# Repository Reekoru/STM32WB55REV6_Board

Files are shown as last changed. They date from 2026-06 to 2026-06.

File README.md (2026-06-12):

# STM32WB55REV6 Custom Development Board

A compact, custom-designed development board for the **STM32WB55REV6** dual-core Bluetooth Low Energy (BLE) and Zigbee microcontroller. Designed in KiCad, this board features a modern USB-C interface for power/data, a dedicated UART interface for debugging, and a space-saving Tag-Connect TC2030 footprint for SWD programming.

## Features

* **MCU:** STM32WB55REV6 (Dual-core Arm® Cortex®-M4 @ 64 MHz with FPU, Cortex-M0+ @ 32 MHz for network/radio).
* **Connectivity:** On-board RF circuitry and antenna for 2.4 GHz BLE 5.4, Zigbee, and Thread.
* **Power:** USB-C connector with TPS78233DDC 3.3V regulator supplying up to 150 mA.
* **Programming/Debugging:** SWD via a headless **Tag-Connect TC2030** footprint (no-legs/legged variant).
* **Serial Communication:** Dedicated UART breakout header for easy terminal debugging.
* **Peripherals:** 
    * 1x User LED (connected to Pin `PB9`)
    * USB-UART (connected to Pin `PA9` [TX], Pin `PA10` [RX])
    * 1x Reset Button, 1x Boot Button
    * External 32.768 kHz LSE Crystal, 32 MHz HSE Crystal

---

## Hardware Overview

### Pinout Configuration

| Interface | Pin Name | STM32WB55 Pin | Description |
| :--- | :--- | :--- | :--- |
| **UART** | TX / RX | PA9 / PA10 | Debug Serial Port |
| **SWD** | SWO / SWDIO / SWCLK | PB3 / PA13 / PA14 | Tag-Connect TC2030 Programming |
| **User LED** | LED1 | PB9 | Active [High/Low] indicator |

### Power Supply
The board is powered via the **USB-C** connector. The input 5V is regulated down to 3.3V for the MCU and RF front end. 
* **Maximum input voltage:** 5.5V
* **Operating voltage:** 3.3V

---

## Programming and Debugging

### Required Hardware
To flash and debug this board, you will need:
1.  An ST-LINK V2, V3, or a Segger J-Link debugger.
2.  A **Tag-Connect TC2030-IDC** (or TC2030-IDC-NL) cable along with the corresponding retaining clip if using the no-legs version.

### SWD Pinout (TC2030 Footprint)
The Tag-Connect footprint maps to the following standard SWD layout:
* Pin 1: VCC (3.3V)
* Pin 2: SWDIO
* Pin 3: NRST (Reset)
* Pin 4: SWCLK
* Pin 5: GND
* Pin 6: SWO (Optional trace capture)

### Flashing via STM32CubeProgrammer
1. Connect the TC2030 cable to the board and your ST-LINK debugger.
2. Open **STM32CubeProgrammer**, select **ST-LINK** as the interface, and click **Connect**.
3. Browse for your compiled binary/hex file and click **Start Programming**.

---

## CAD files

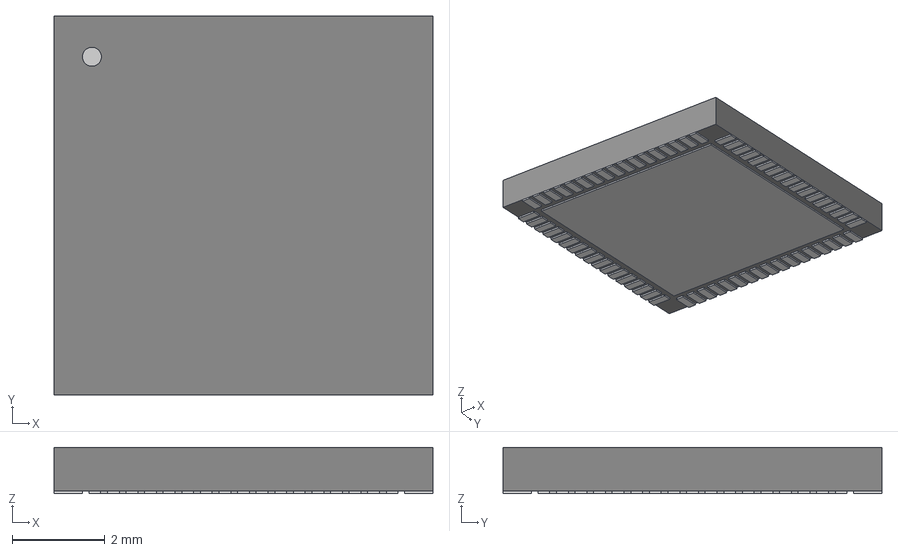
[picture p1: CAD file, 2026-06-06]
STM32WB55REV6/VFQFN68-8x8mm.step
8.15 x 8.15 x 0.993 mm

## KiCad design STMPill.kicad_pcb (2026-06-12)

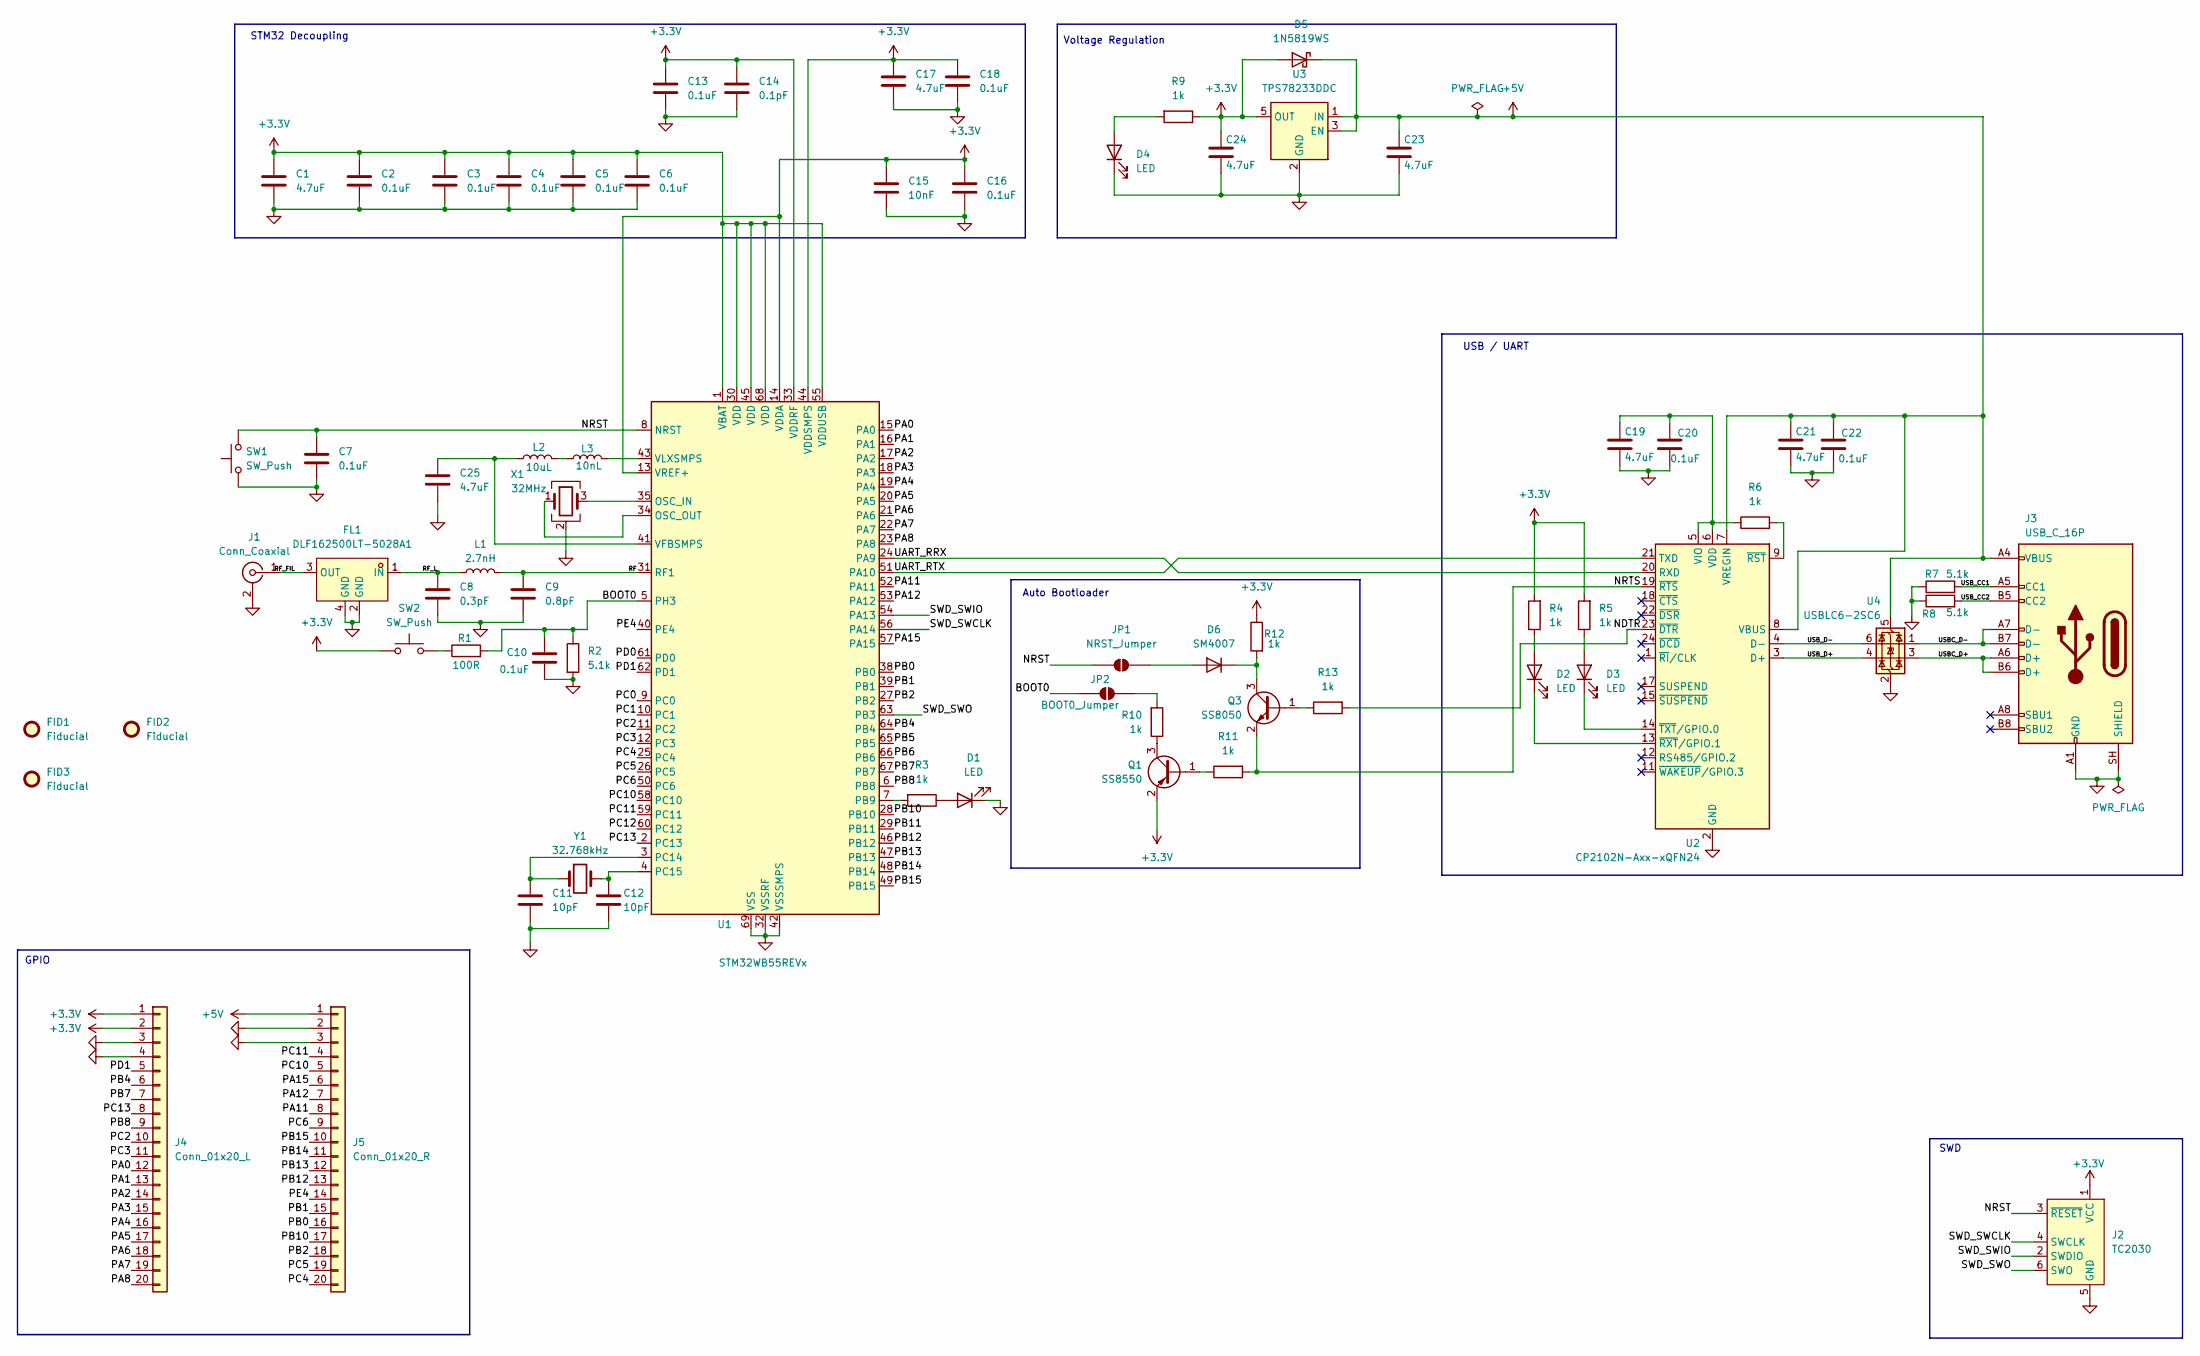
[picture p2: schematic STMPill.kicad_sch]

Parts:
C1, C17, C19, C21, C23, C24, C25: 4.7uF; C_0402_1005Metric; LCSC Part C23733
C2, C3, C4, C5, C6, C7, C10, C13, C16, C18, C20, C22: 0.1uF; C_0402_1005Metric; LCSC Part C1525
C8: 0.3pF; C_0402_1005Metric; LCSC Part C92338
C9: 0.8pF; C_0402_1005Metric; LCSC Part C76988
C11, C12: 10pF; C_0402_1005Metric; LCSC Part C1845716
C14: 0.1pF; C_0402_1005Metric; LCSC Part C53273
C15: 10nF; C_0402_1005Metric; LCSC Part C1525
D1, D3, D4: LED; D_0402_1005Metric; LCSC Part C598352
D2: LED; D_0402_1005Metric; LCSC Part C130720
D5: 1N5819WS; D_SOD-323; LCSC Part C191023
D6: SM4007; D_SOD-123F; LCSC Part C64898
FID1, FID2, FID3: Fiducial; Fiducial_0.5mm_Mask1mm
FL1: DLF162500LT-5028A1; FILTER-SMD_0603-4P-L1.6-W0.8-L-1; MPN DLF162500LT-5028A1; LCSC Part C531364
J1: Conn_Coaxial; U.FL_Hirose_U.FL-R-SMT-1_Vertical; LCSC Part C88374
J2: TC2030; Tag-Connect_TC2030-IDC-FP_2x03_P1.27mm_Vertical
J3: USB_C_16P; USB_C_Receptacle_GCT_USB4105-xx-A_16P_TopMnt_Horizontal; LCSC Part C165948
J4: Conn_01x20_L; PinSocket_1x20_P2.54mm_Vertical
J5: Conn_01x20_R; PinSocket_1x20_P2.54mm_Vertical
JP1: NRST_Jumper; SolderJumper-2_P1.3mm_Open_RoundedPad1.0x1.5mm
JP2: BOOT0_Jumper; SolderJumper-2_P1.3mm_Open_RoundedPad1.0x1.5mm
L1: 2.7nH; L_0402_1005Metric; LCSC Part C77108
L2: 10uL; L_0805_2012Metric; LCSC Part C162582
L3: 10nL; L_0402_1005Metric; LCSC Part C3911026
Q1: SS8550; SOT-23; LCSC Part C8542
Q3: SS8050; SOT-23; LCSC Part C2150
R1: 100R; R_0402_1005Metric; LCSC Part C25076
R2, R7, R8: 5.1k; R_0402_1005Metric; LCSC Part C25905
R3, R4, R5, R6, R9, R10, R11, R12, R13: 1k; R_0402_1005Metric; LCSC Part C11702
SW1, SW2: SW_Push; KEY-SMD_L3.9-W3.0-LS5.0-EH; LCSC Part C18078117
U1: STM32WB55REVx; QFN-68-1EP_8x8mm_P0.4mm_EP6.4x6.4mm; LCSC Part C1558409
U2: CP2102N-Axx-xQFN24; QFN-24-1EP_4x4mm_P0.5mm_EP2.6x2.6mm; LCSC Part C969151
U3: TPS78233DDC; SOT-23-5; LCSC Part C14878
U4: USBLC6-2SC6; SOT-23-6; LCSC Part C7519
X1: 32MHz; Crystal_SMD_2016-4Pin_2.0x1.6mm; LCSC Part C843260
Y1: 32.768kHz; SMD3215-2P; LCSC Part C7294751

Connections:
+3.3V: C1.1, C2.1, C3.1, C4.1, C5.1, C6.1, C13.1, C14.1, C15.1, C16.1, C17.1, C18.1, C24.1, D5.2 (A), J2.1 (VCC), J4.1, J4.2, Q1.2 (E), R4.2, R5.2, R9.1, R12.1, SW2.1, U1.1 (VBAT), U1.13 (VREF+), U1.14 (VDDA), U1.30 (VDD), U1.33 (VDDRF), U1.44 (VDDSMPS), U1.45 (VDD), U1.55 (VDDUSB), U1.68 (VDD), U3.5 (OUT)
+5V: C21.1, C22.1, C23.1, D5.1 (K), J3.A4 (VBUS), J3.A9 (VBUS), J3.B4 (VBUS), J3.B9 (VBUS), J5.1, U2.7 (VREGIN), U2.8 (VBUS), U3.1 (IN), U3.3 (EN), U4.5 (VBUS)
/BOOT0: C10.1, JP2.1 (A), R1.2, R2.1, U1.5 (PH3)
/NDTR: R13.2, U2.23 (~DTR)
/NRST: C7.1, J2.3 (~RESET), JP1.1 (A), SW1.2, U1.8 (NRST)
/NRTS: Q3.2 (E), R11.2, U2.19 (~RTS)
/PA0: J4.12, U1.15 (PA0)
/PA1: J4.13, U1.16 (PA1)
/PA2: J4.14, U1.17 (PA2)
/PA3: J4.15, U1.18 (PA3)
/PA4: J4.16, U1.19 (PA4)
/PA5: J4.17, U1.20 (PA5)
/PA6: J4.18, U1.21 (PA6)
/PA7: J4.19, U1.22 (PA7)
/PA8: J4.20, U1.23 (PA8)
/PA11: J5.8, U1.52 (PA11)
/PA12: J5.7, U1.53 (PA12)
/PA15: J5.6, U1.57 (PA15)
/PB0: J5.16, U1.38 (PB0)
/PB1: J5.15, U1.39 (PB1)
/PB2: J5.18, U1.27 (PB2)
/PB4: J4.6, U1.64 (PB4)
/PB5: U1.65 (PB5)
/PB6: U1.66 (PB6)
/PB7: J4.7, U1.67 (PB7)
/PB8: J4.9, U1.6 (PB8)
/PB10: J5.17, U1.28 (PB10)
/PB11: U1.29 (PB11)
/PB12: J5.13, U1.46 (PB12)
/PB13: J5.12, U1.47 (PB13)
/PB14: J5.11, U1.48 (PB14)
/PB15: J5.10, U1.49 (PB15)
/PC0: U1.9 (PC0)
/PC1: U1.10 (PC1)
/PC2: J4.10, U1.11 (PC2)
/PC3: J4.11, U1.12 (PC3)
/PC4: J5.20, U1.25 (PC4)
/PC5: J5.19, U1.26 (PC5)
/PC6: J5.9, U1.50 (PC6)
/PC10: J5.5, U1.58 (PC10)
/PC11: J5.4, U1.59 (PC11)
/PC12: U1.60 (PC12)
/PC13: J4.8, U1.2 (PC13)
/PD0: U1.61 (PD0)
/PD1: J4.5, U1.62 (PD1)
/PE4: J5.14, U1.40 (PE4)
/RF: C9.1, L1.2, U1.31 (RF1)
/RF_FIL: FL1.3 (OUT), J1.1 (In)
/RF_L: C8.1, FL1.1 (IN), L1.1
/SWD_SWCLK: J2.4 (SWCLK), U1.56 (PA14)
/SWD_SWIO: J2.2 (SWDIO), U1.54 (PA13)
/SWD_SWO: J2.6 (SWO), U1.63 (PB3)
/UART_RRX: U1.24 (PA9), U2.20 (RXD)
/UART_RTX: U1.51 (PA10), U2.21 (TXD)
/USBC_D+: J3.A6 (D+), J3.B6 (D+), U4.3 (I/O2)
/USBC_D-: J3.A7 (D-), J3.B7 (D-), U4.1 (I/O1)
/USB_CC1: J3.A5 (CC1), R7.2
/USB_CC2: J3.B5 (CC2), R8.2
/USB_D+: U2.3 (D+), U4.4 (I/O2)
/USB_D-: U2.4 (D-), U4.6 (I/O1)
GND: C1.2, C2.2, C3.2, C4.2, C5.2, C6.2, C7.2, C8.2, C9.2, C10.2, C11.2, C12.2, C13.2, C14.2, C15.2, C16.2, C17.2, C18.2, C19.2, C20.2, C21.2, C22.2, C23.2, C24.2, C25.2, D1.1 (K), D4.1 (K), FL1.2 (GND), FL1.4 (GND), J1.2 (Ext), J2.5 (GND), J3.A1 (GND), J3.A12 (GND), J3.B1 (GND), J3.B12 (GND), J3.SH (SHIELD), J4.3, J4.4, J5.2, J5.3, R2.2, R7.1, R8.1, SW1.1, U1.32 (VSSRF), U1.42 (VSSSMPS), U1.69 (VSS), U2.2 (GND), U2.25 (GND), U3.2 (GND), U3.4 (GND), U4.2 (GND), X1.2 (G), X1.4 (G)
unnamed: D1.2 (A), R3.1
unnamed: D2.2 (A), R4.1
unnamed: D2.1 (K), U2.13 (~RXT/GPIO.1)
unnamed: D3.2 (A), R5.1
unnamed: D3.1 (K), U2.14 (~TXT/GPIO.0)
unnamed: D4.2 (A), R9.2
unnamed: D6.2 (A), JP1.2 (B)
unnamed: D6.1 (K), Q3.3 (C), R12.2
unnamed: JP2.2 (B), R10.2
unnamed: L2.2, L3.1
unnamed: Q1.1 (B), R11.1
unnamed: Q1.3 (C), R10.1
unnamed: Q3.1 (B), R13.1
unnamed: R1.1, SW2.2
unnamed: U1.35 (OSC_IN), X1.3
unnamed: U1.34 (OSC_OUT), X1.1
unnamed: R3.2, U1.7 (PB9)
unnamed: C11.1, U1.3 (PC14), Y1.1
unnamed: C12.1, U1.4 (PC15), Y1.2
unnamed: C25.1, L2.1, U1.41 (VFBSMPS)
unnamed: L3.2, U1.43 (VLXSMPS)
unnamed: C19.1, C20.1, R6.1, U2.5 (VIO), U2.6 (VDD)
unnamed: R6.2, U2.9 (~RST)

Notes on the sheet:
Auto Bootloader
STM32 Decoupling
GPIO
USB / UART
Voltage Regulation
SWD

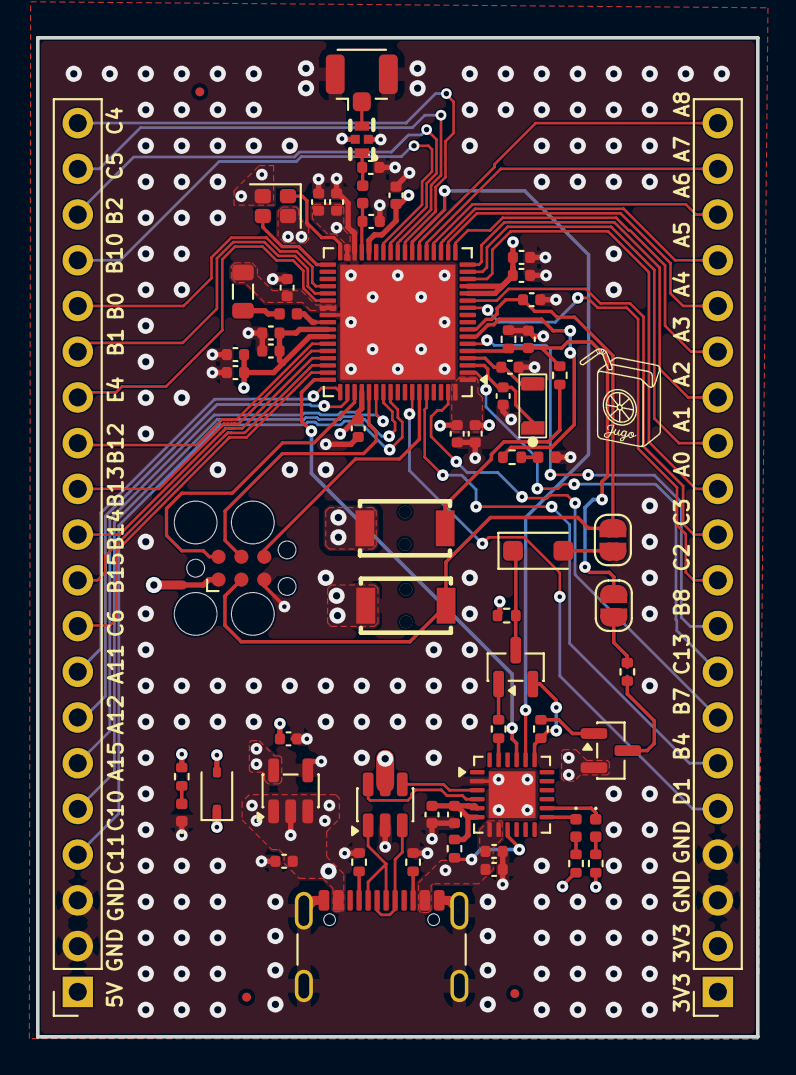
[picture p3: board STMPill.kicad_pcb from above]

Board: 4 copper layers, 40.0 x 55.5 mm, 68 parts (0 on the bottom side), 77 nets.
